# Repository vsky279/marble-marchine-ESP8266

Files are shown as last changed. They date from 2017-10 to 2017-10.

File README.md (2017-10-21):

# Motorized version of the 3D Printed Marble Machine #3

## Intro
This is a motorized version of the 3D Printed Marble Machine #3. 
The model is also published on [thingiverse](https://www.thingiverse.com/thing:2555714) and this is the [original](https://www.thingiverse.com/thing:1385312) manual version.

It is 60% size of the original. If you have already one printed (in this size) it can be even upgraded to the motorized version by making a hole in the middle, changing the spiral and adding the base.

### Video
Motorized version of the 3D Printed Marble Machine #3 (http://www.youtube.com/watch?v=hlU-JsbdjHA)

## Parts

STL models are in the folder [stl](./stl).
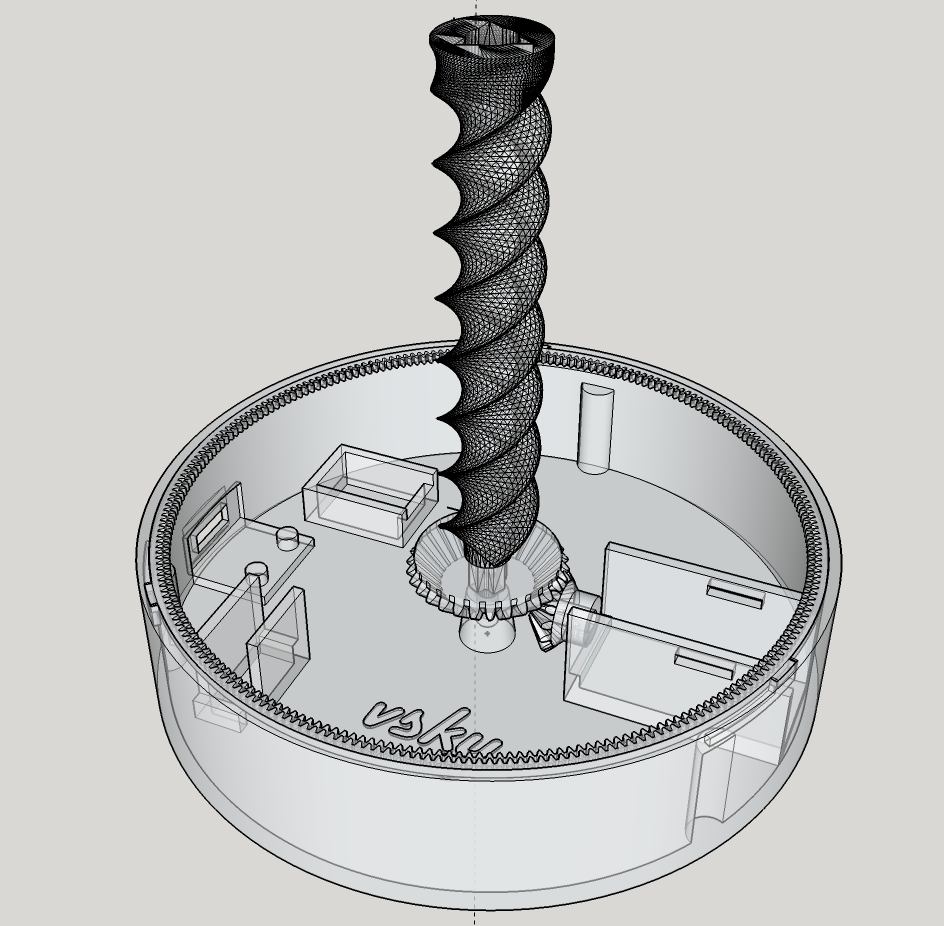
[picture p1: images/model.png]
model


## Electronics
### Parts
* Motor 3-6V DC Small Micro Speed Reduction Geared Box Electric Motor 40RPM
* ESP8266 ESP-01
* MICRO USB to DIP Adapter 5pin female connector B type pcb converter
* 5V to 3.3V Step-Down Power Supply Module AMS1117-3.3 LDO 800MA
* Transistor BC548
* Resistor 10K (pull-up resistor) and 1K connected to the base of the transistor
* Diode 1N4004

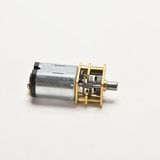
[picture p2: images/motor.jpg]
motor
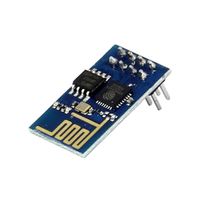
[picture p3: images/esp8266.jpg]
esp8266
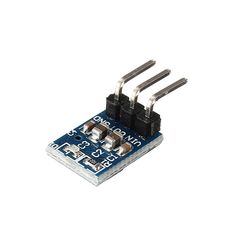
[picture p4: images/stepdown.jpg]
stepdown


### Scheme

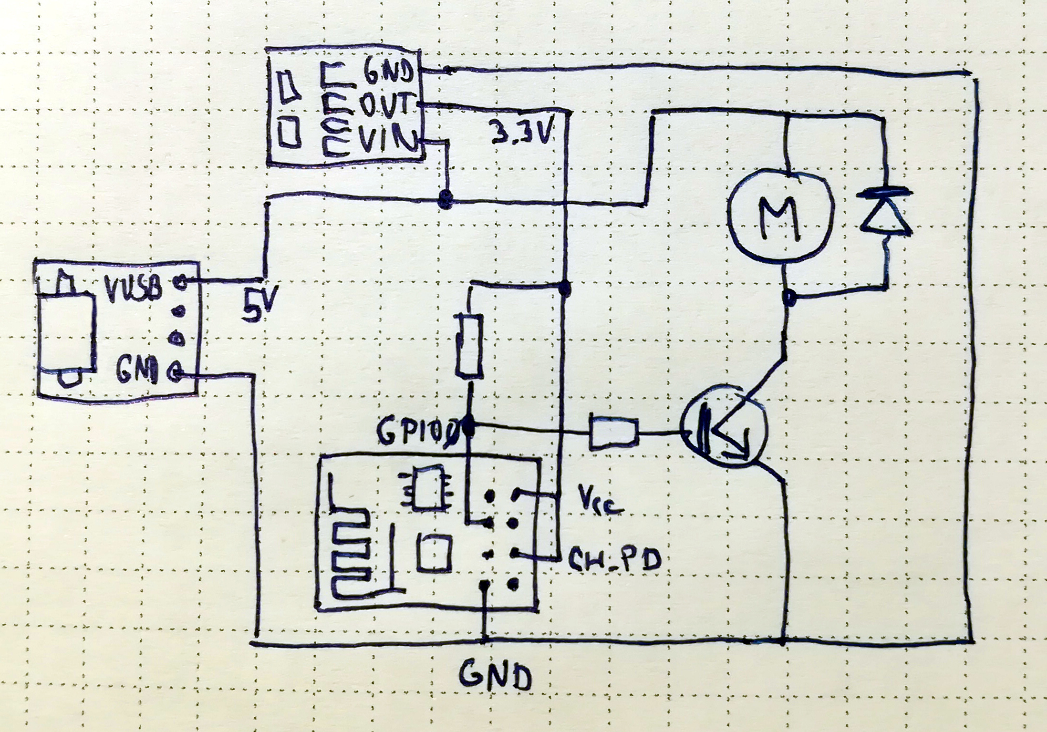
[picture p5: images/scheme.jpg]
scheme


## Programming

The main chip is ESP8266. I am using NodeMCU Lua ([https://github.com/nodemcu/nodemcu-firmware](https://github.com/nodemcu/nodemcu-firmware)) to program the ESP8266. The programming in Lua is very easy so the core program can have less than 120 lines including the web server to control the machine.

A [NodeMCU custom builds](https://nodemcu-build.com/) tool can be used to compile the binary for ESP8266. Beside standard modules the following modules are used: `cron, enduser_setup, pwm, rtctime, sntp`. I have used the integer version of the firmware is used. Though float version should be fine too.

I am using [ESP8266 Flasher](https://github.com/nodemcu/nodemcu-flasher) to flash the binary.

To upload Lua files and files used by the web server the [ESPlorer](https://esp8266.ru/esplorer/) GUI can be used. These files are in the folder (lua_code)[./lua_code]).

The speed can be adjusted by PWM regulation. The power is supplied via micro USB so any phone adapter can be used.

The program connects to the WIFI, synchronizes time and runs the motor every 15 minutes for short period and for 5 seconds every hour between 7am and 11pm. Actually it also checks whether I am at home by pinging my phone. If this functionality is required the `net_info` module has to be included. It isavailable here: https://github.com/vsky279/nodemcu-firmware/tree/ping. It is not deployed in the `dev` version so it needs to be included manually and compiled locally.

Beside the web server, ESP8266 exposes also a telnet server so an OTA-like update of Lua codes can be performed.

## Assembly
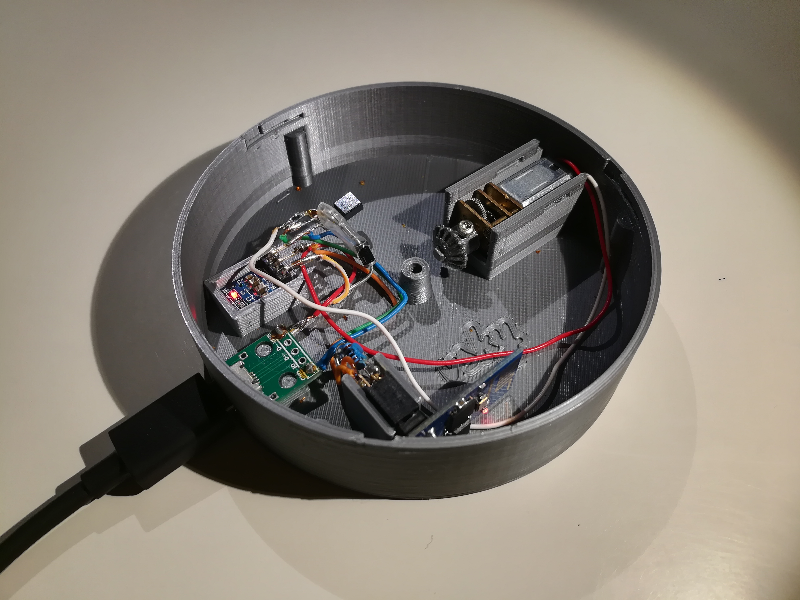
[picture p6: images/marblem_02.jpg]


The [ring](./stl/ring.stl) is used to lock the base to the track.

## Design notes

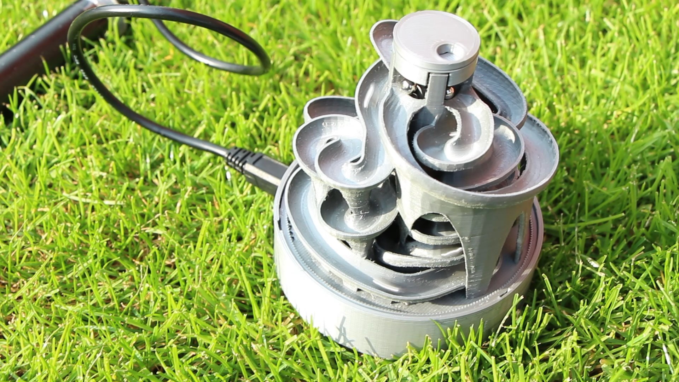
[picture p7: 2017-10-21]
images/marblem_01.jpg

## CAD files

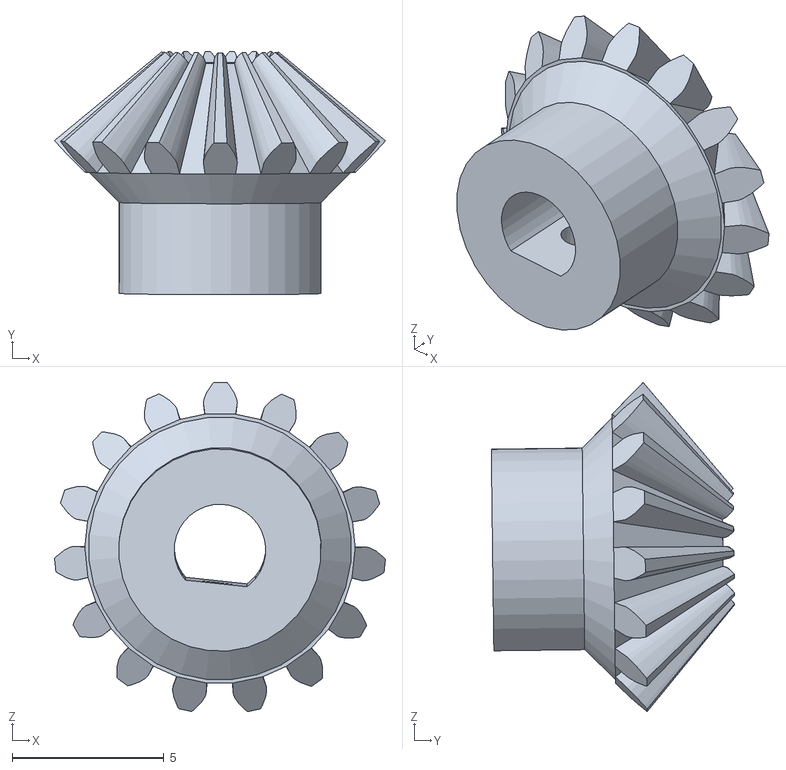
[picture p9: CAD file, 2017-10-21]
stl/gear1.stl
10.9 x 8.03 x 10.9

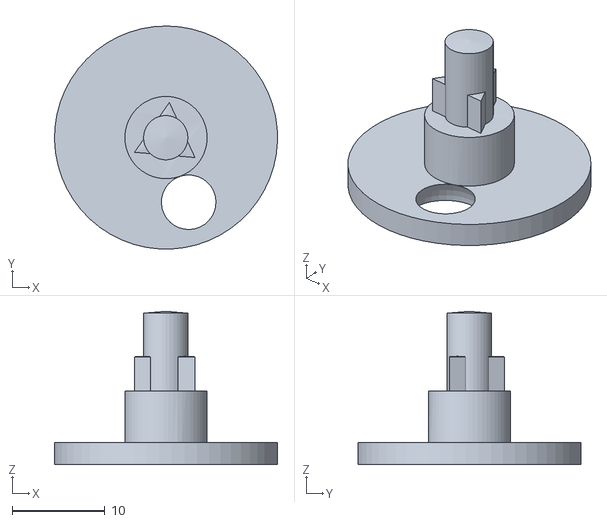
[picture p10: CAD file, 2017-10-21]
stl/turncap 60pct.stl
24.0 x 24.0 x 16.5

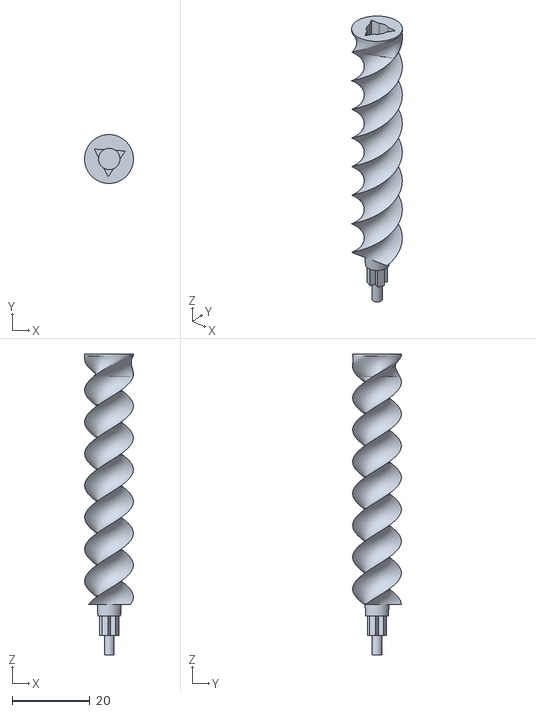
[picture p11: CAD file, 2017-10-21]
stl/spiral.stl
12.6 x 12.6 x 77.5

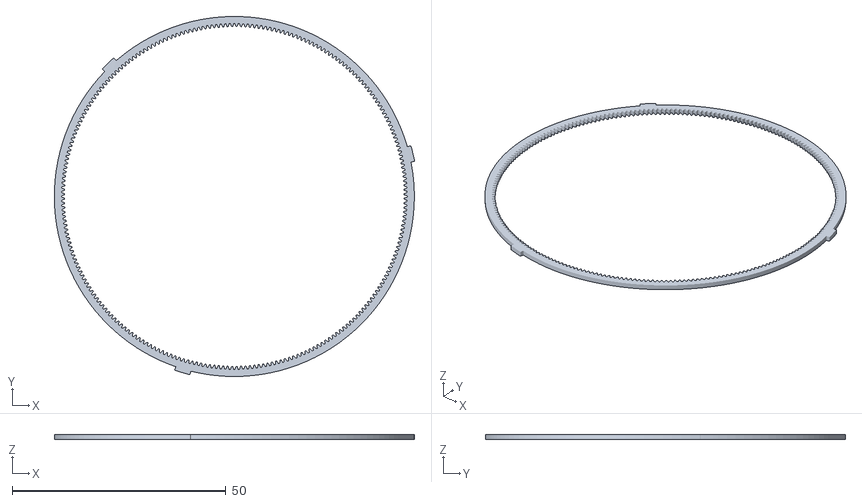
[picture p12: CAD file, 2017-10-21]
stl/ring.stl
84.2 x 84.1 x 1.17

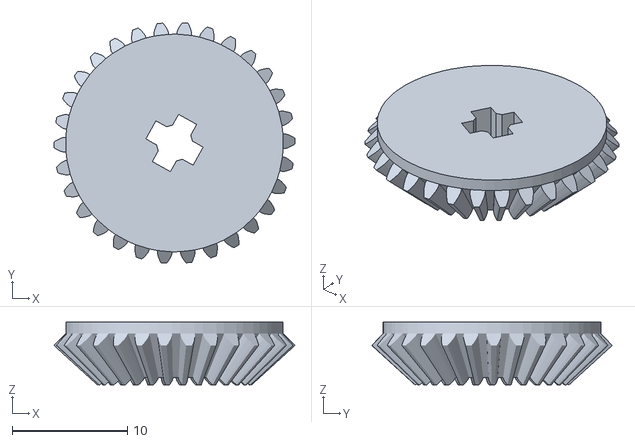
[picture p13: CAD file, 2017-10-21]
stl/gear2.stl
20.9 x 20.9 x 5.45

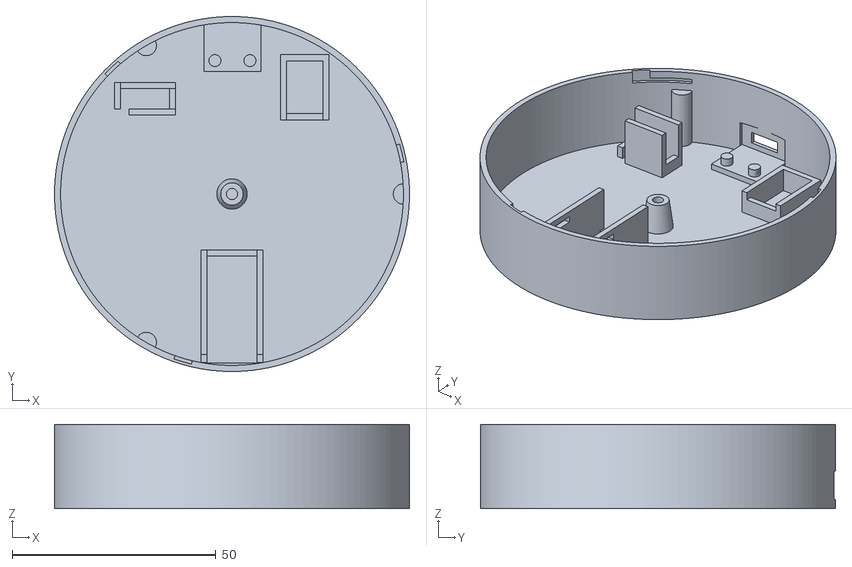
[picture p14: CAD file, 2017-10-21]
stl/base.stl
87.2 x 87.2 x 20.7

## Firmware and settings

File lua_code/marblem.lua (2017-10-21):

local n=require("ntp")

local PIN = 3
local speed = 1023

local pwm_setup, pwm_start, pwm_stop, pwm_setduty = pwm.setup, pwm.start, pwm.stop, pwm.setduty
local tmr_alarm, tmr_unregister, tmr_ALARM_SINGLE, tmr_ALARM_AUTO, tmr_create = tmr.alarm, tmr.unregister, tmr.ALARM_SINGLE, tmr.ALARM_AUTO, tmr.create
local string_find, string_gmatch, string_format, string_sub, string_gsub = string.find, string.gmatch, string.format, string.sub, string.gsub
local gpio_mode, gpio_serout, gpio_write, gpio_HIGH, gpio_LOW, gpio_OUTPUT = gpio.mode, gpio.serout, gpio.write, gpio.HIGH, gpio.LOW, gpio.OUTPUT

local tmr_stop = tmr_create()
local tmr_tug = tmr_create()
local tmr_sync = tmr_create()

local last_seen = 0

gpio_mode(PIN, gpio_OUTPUT)
gpio_write(PIN, gpio_LOW)

function turn(time, duty)
  duty = duty or speed
  time = time or 1000
  pwm_setup(PIN, 2000, 1023)
  pwm_start(PIN)
  tmr_alarm(tmr_tug, 100, tmr_ALARM_SINGLE, function() return pwm_setduty(PIN, duty) end)
  tmr_alarm(tmr_stop, time, tmr_ALARM_SINGLE, function() return pwm_stop(PIN) end)
end

function timeSync()
	n:syncdns(function () return tmr_alarm(tmr_sync, 90*60*1000, tmr_ALARM_AUTO, timeSync) end,
		function() return tmr_alarm(tmr_sync, 10*1000, tmr_ALARM_SINGLE, timeSync) end)
end
timeSync()

function ping()
  print("time: ", n:format(), n:format(last_seen))
  local cnt = 1
  net_info.ping("brick.lan", cnt, function (b, ip, sq, ttl, tm) 
    print(string.format("%d bytes from %s, icmp_seq=%d ttl=%d time=%dms", b, ip, sq, ttl, tm)) 
    cnt = cnt - 1
    if b > 0 then last_seen = n:time() end
  end)
end
cron.schedule("*/2 * * * *", ping)

function cronhandler(e)
  local T=n:time()
  local gmt = n:ts2gmt(T)
  print("time: ", n:format(T), n:format(last_seen))
  local hour, minute = gmt[4], gmt[5]
  if (T - last_seen < 3600) and ((hour >= 7 and hour <=23) or (hour == 0 and minute == 0)) then
    if minute == 0 then -- full hour
      --(hour - 1) % 12 + 1
      turn(5000)
    else
      turn(500 * minute / 15)
    end
  end
end
cron.schedule("*/15 * * * *", cronhandler)

srv=net.createServer(net.TCP)
srv:listen(80,function(conn)
  conn:on("receive", function(client, request)
    local _, _, method, path, vars = string_find(request, "([A-Z]+) (.+)?(.+) HTTP")
    if(method == nil)then
        _, _, method, path = string_find(request, "([A-Z]+) (.+) HTTP")
    end
    print("request: ", method, path, vars)
    path = string_sub(path, 2) -- remove first char, i.e. "/"
    local index = (path == "")
    path = index and "index.html" or path
    local fd = file.open(path, "r")
    if not fd then 
        client:send("HTTP/1.0 404 Not Found\r\n\r\n404 Not Found\r\n") 
        return
    end
    if index then
      local _GET = {}
      if (vars ~= nil)then
          for k, v in string_gmatch(vars, "(%w+)=(%w+)&*") do
              _GET[k] = v
          end
      end
      local _GET_time, _GET_speed = _GET.time, _GET.speed
      _GET = nil
      if(_GET_time and _GET_speed) then
        print("turn: ", _GET_speed, _GET_time)
        turn(_GET_time * 1000, _GET_speed)
      end

      local line, content = "", ""
      while line do
          line = string_gsub(line, "$TIME", _GET_time or 5)
          line = string_gsub(line, "$SPEED", _GET_speed or speed)
          content = content .. line
          line = fd:readline()
      end
      fd:close()
      if content then 
        client:send(content, function (c) 
          c:close() 
          c:on("sent", nil)
        end) 
      end
    else
      local function sendfile()
        local line=fd:read(1024)
        if line then
          client:send(line, sendfile)
        else
          fd:close()
          client:close()
          client:on("sent", nil)
        end
      end
      sendfile()
    end
  end)
end)

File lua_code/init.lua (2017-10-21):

local fn="marblem"
local smph = "semaphore.tmp"

local tmr_create, tmr_alarm, tmr_ALARM_SINGLE = tmr.create, tmr.alarm, tmr.ALARM_SINGLE

gpio.mode(3, gpio.OUTPUT);
gpio.write(3, gpio.LOW);

local function con(t)
  local cred = {yourwifi="password"}
  for ssid, _ in pairs(t) do
    if cred[ssid] then
      print("SSID: "..ssid)
      wifi.sta.config({ssid=ssid, pwd=cred[ssid]})
      wifi.sta.connect()
      return
    end
  end
  enduser_setup.start();
end

local function disarm()
    print("disarming semaphore")
    file.remove(smph)
end

print("Setting up WIFI...")
wifi.setmode(wifi.STATION)
wifi.setphymode(wifi.PHYMODE_G)
wifi.sta.getap(con, 1)
tmr_alarm(0,1000,1,function() 
  if wifi.sta.getip()== nil then 
    print("IP unavailable...") 
  else 
    tmr.stop(0)
    print("IP: "..wifi.sta.getip())
    print("Starting "..fn.." in 1 seconds")
        tmr_alarm(0, 1000, 0, function() 
            print("telnet")
            require("telnet")
            if not file.exists(smph) then
                file.open(smph, "w"):close()
                tmr_create():alarm(60000, tmr_ALARM_SINGLE, disarm)
                print(fn)
                require(fn)
            else
              print("semaphore armed - stopping")
              tmr_restart=tmr_create()
              tmr_restart:alarm(600000, tmr_ALARM_SINGLE, function()
                  disarm()
                  node.restart()
              end)
            end
        end)
  end 
end)
